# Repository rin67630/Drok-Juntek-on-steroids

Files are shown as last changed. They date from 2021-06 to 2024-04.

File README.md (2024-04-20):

# Drok&Juntek on steroids.
Extend the possibilities of cheap digital power supplies with an ESP32 WiFi module

N.B.   The Software part is now on  
https://github.com/rin67630/Soft-Power2-MPPT  
cu there...

Juntek (aka MingHe) and Drok (maybe others e.g Ming-He) sell some interesting cheap programmable buck converter modules e.g.:
- DPS3806         (60V/6A boost/buck converter) https://www.aliexpress.com/item/1005001591485527.html
- Buck3603        (36V/3A buck converter) https://www.aliexpress.com/item/32872687512.html
- BST900          (36V/90V boost converter https://www.aliexpress.com/item/1005002006504263.html
- Drok low Power  (60V/8A buck converter) https://www.aliexpress.com/item/32862110549.html  
- Drok high power (80V/12A buck converter) https://www.aliexpress.com/item/32863179021.html  
*(links only given to identify the modules, you are encouraged to procure the devices from your favourite source)  

They are all controlled by a pluggable control board, which stages a STM microcontroller and a 4x7 digit LED display.  
The 4 push-buttons to control the operations are clumsy and the seven segment display is everything but comfortable.  


My idea was to get rid of the original control module, and to replace it by an ESP32 WiFi enabled microcontroller in order to boost it's usability,
give full internet control and provide tons of features... 

Drok and Juntek are using the same analog control principle:  on the left side, the connector gets two PWM control inputs (voltage and current) and deliver two corresponding analog control feedback outputs all in the range 0..2,1V.  
On the right side, the connector provides GND and 5V at ~200mA.  

I used a TTGO ESP32 with an integrated TFT color display plugged onto a 6x8cm prototyping board as an adapter on a Drok 6008  
showing the web interface on a smartphone:   
  
Here the version with a PCB on a Drok6012 with input and load current probes and a rotary encoder on the extension port:   


The BOM for the upgrade cost less than 20$ (the ESP TTGO, an ADS1115 module, a prototyping board, some pin headers, a few resistors and condensators...)  

## The fun can begin!
Recycling a big part of the software resources of https://github.com/rin67630/Soft-Power-MPPT, I am providing much more than just a simple programmable power supply.

### Power supply mode
The power supply is controllable by:   
- USB -Serial with a simple menu to change the set-points control, the OLED display variants, the charging profiles and print reports.  
- from everywhere in the world using the cloud dashboard service of https://thinger.io with a free limited maker account.  
This is just an example, much more will come:  


 
- using the integrated buttons of the TTGO and/or an optional rotary knob to make it more comfortable to control.  
- can optionally be remotely controlled by another "slave" TTGO module in the same WiFi area.

Over the serial port and thinger.io, many reports will be made available:  
- Energy report by the second, the minute, the hour.
- Ah, Wh Joule/Coulomb reports by the minutes, the hour, the day.
- Events of the charging process
- ...  

Beside the usual constant voltage and constant current set points, I will provide many interesting things that are not common, but very useful:

### MPPT Solar charger:
cf: https://github.com/rin67630/Soft-Power2-MPPT

### Battery Charger mode: (1)  
- charging profiles for many battery chemistries
- evaluation of the battery's internal resistance
- evaluation of the battery' capacity
- charging time series plots

### Power Source emulation: (1)  
- add a programmable internal resistance
- run a constant power mode
- emulation of solar panel / wind turbine incuding "pseudo-daily" gaussian cycles (accelerated 60x) to test solar chargers

### Programmable Load (for the Juntek buck-boost version) (1)  
- together with a flooder to dissipate the energy, the buck-boost converter can be used to discharge batteries and transfer energy from one battery to another one.  

### Maybe other useful ideas that you might have...

Last but not least everything is neatly self powered, and integrated on one single board, that plugs instead of the original controller board.  
If you wanted to revert to the original functionality, just replug the manufacturer's control board.  
There is absolutely no cable mess and even a new program can be updated over the air using a beginner's easy Arduino IDE.  
You need no additional computer to manage the dashboards, everything is done in the cloud.  
The only thing you need, is a Wifi connection.  

(1) not yet finalized...

You are invited to discuss your personal project on Discord:  
https://discord.gg/gcmSpHH3bX  (Multi purpose Hardware)  
https://discord.gg/eY5H6PMqfk  (Specific application as a MPPT Solar Charge Controller).  

Cu there!

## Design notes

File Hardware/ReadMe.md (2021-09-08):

This folder contains the schematics and hardware description of my Drok-Juntek-on-steroids solution. 

# History
On a first approach V1.0, I have used a passive circuitry with resistors and capacitors to adapt the signal levels to the ADCs of the ESP32 and -to a certain extent- compensate the intrinsic deficits of the ESP32 ADCs.  
(You can take a look at the ReadMeV1.md if you are interested)

# V2.0 

Finally with V2.0 I decided to use an I2C 16bit, 4 channel ADC  ADS1115 module to replace the very low quality ADCs of the ESP32.    
With this module, conveniently placed under the TTGO, everything becomes much easier.
This new solution uses less components, is much more precise, factory calibrated and the measuring ranges can be determined by software.
The design uses standard buck converters, an ESP32 TTGO TFT module, simple prototyping boards and a few resistors/condensators. 

 ## Bill of materials Off Board

- Juntek DSP 3606 / Drok 
- TTGO ESP32 TFT board
- ADS1115 external ADC board
- 4 x 6 cm prototyping board
- 1 x 3,3MM resistor to measure up to 58V Vin for Drok, 2k resistor to measure Vin for JuntekD3806, nothing for Juntek B3603.

 ## Bill of materials On Board


## Header pinouts (comparison between Juntek / Drok)
  

**N.B.** If you can, order female pin headers with long pins. The ESP32's socket must be soldered higher than the one of the ADS1115.  

To a certain extend it is doable with regular female headers too:  
On the ADS1115 solder the male pin headers normally, then remove the plastic part of them and cut the pins 5mm shorter.  
That way, the ADS1115 PCB sits directly on the female headers. 
Solder the female headers of the ESP32 with some space between the board and the plastic.  
That lets enough room to piggy-back both modules.  



An easier solution is to procure long male pin headers for the TTGO:
https://www.ebay.de/itm/323404971458?var=512467637501

Low profile headers for the ADS1115 are possibel too, but these are not common and quite expensive.

## Proto Wiring
It's relativly easy to wire the adapter to a prototyping board:
### Top view (component side)


The prototype is universal and fits Juntek/MingHe  and Drok DC/DC conveters.
Since they have some slight difference in the left connector, I have used jumpers.

## PCB
a PCB is now on the final stage... (Thanks to TechColab).
The PCB is designed universal for all supported DC-DC converters.





n.b. The 470μF condensator is wired horizontal, we did not have a KiCAD library for that, so it is hot rendered.
The patch fields are shown empty, normally you just will wire a few wires directly but you may poulate them with 90° headers and use prototype jumpers.
On the west side w have 2 header connectors with the analog and control pins, useful for hooking measuring probes.



Who wants raw PCBs should send me his (her) address at lazlo.lebrun < you know what to insert > gmail.com,  
I would appreciate a participation of 1€ per PCB and the postage cost (2€ for Europe), i'll mail you the different PayPal address in return.

## Schematic diagram


# V1.0 
V1.0 is obsolete, that old version used the ESP32 only as ADC and was REALLY inaccurate, see ReadMeV1.md

Enjoy!

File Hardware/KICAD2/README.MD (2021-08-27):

New optimized PCB layout Courtesy paulvdh@forum.KiCAD.info.

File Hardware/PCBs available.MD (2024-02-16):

Some of us have ordered PCBs by ten pieces and have many left.  

If you need a PCB, we will be happy to send one or two just for postage.
you may ask me or other fellowes
- lazlo.lebrun <at> gmail.com  (DE)
- michel.firholz <at> live.de (DE)

If you have PCBs to distribute especially if you are located in other countries and agree to participate, let me know.

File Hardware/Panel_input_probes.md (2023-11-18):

# Panel input Probes

With the exception of the J3603 the DC-DC converters used do not provide a measurement of the panel voltage, nor its current.  
The input voltage value is however essential to control the MPPT. 
The input current is nice to have.  
Most DC-DC converters feed back the output power to the input (the solar panel) which is first wasting a part of energy when the panel does not produce current, 
secondly an inadvertent short on the panel while the battery is connected will be an irresistible call for the magic smoke.
So we will need a diode to block the backfeed current.

Since the panel voltages and current can be pretty high the circuit for them is located away from the control board with resistors limiting the energy fed to the inputs.

All these functions will be realised in two input probes connected just before the inputs of the motherboard.



## Voltage probe + blocking diode.

The 10A Schottky diode will be directly soldered to a fork terminal for screws. On the other side the input cable will be soldered to the diode with the feed back resistor (the high side of the input voltage divisor) and finally both sides are wrapped with thermo sleeves:


## Current probe
I have used two 0.05 smd resistors in // (for mechanical stabilty) soldered to a fork terminal and to the input wire at the other side (the fork is folded to fit into the tube and unfolded after) then glued everything in a hard plastic tube. On the shunt, i have a 1kΩ resistor in series to limit the damage if the shunt burns through. Finally both sides are wrapped with thermo sleeves:


  :

And finally going to the side of my adapter board:  


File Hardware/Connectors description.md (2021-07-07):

# Connectors description

## Motherboard right connector
Luckily, the motherboard right connector has the same pinout for every DC/DC converter:
from the top to the bottom you have a 4 ground connections, 2 +5V connections ( that can approximately supply 100mA) and Tx-Rx pins, that are forwarded to the corresponding Tx-Rx connector on the motherboard.  
2 capacitors C8 and C7 will reduce the impact of the power surges from the RF-transmission to the motherboard.  


## Motherboard left connector
the motherboard left connector is not completely standardised, from the top to the bottom the three first pins carry the feedback signals for the output voltage and the output current at various locations, depending on the board make. One board has a feedback of the input voltage, most don't.  
For that reason, there adapter board will have some jumpers to marshall the signals accordingly to the A2, A3, A1 analog inputs of the ADS1115.  


## Feedback of Input voltage or current
On the Juntek 3603, the feedback of the input voltage already exists on pin3 of the left connector.  
On the Juntek 3806, the feedback of the input voltage is not provided, but the pin 3 of the left connector is free, so one can solder a feedback resistor on the motherboard.   
On DROK modules, the pin 3 is not free, so one must go over a side header to provide voltage feedback.  
The current feedback ( optional ) is always to be provided over a side header to ADC0.     

## Extension headers

the standard layout provides two extension headers:
- A Grove-compatible extension header
- A universal extension header

### Grove-compatible extension header
The Grove-compatible extension header uses the standard pinout of the Grove I2C ecosystem adding supplementary ground line and a +5V
on the prototyping board this connector is at the 2.54mm pitch, on the future PCB it should use the Grove system 2mm pitch.


### Universal extension header
The universal extension header exposes all still unused IO lines DAC/ADC lines, the I2C port and some power supply lines.
The (potential) applications are: 
- Rotary control
- I2C keyboard
- Additional I2C sensors (e.g. battery temperature, load currents, light intensity, non-related measurements )
- Additional controls like Load on-off, (I have an extension load control module with 3 FETs and 3 current/voltage feed-back measures in planing)
- and even the potential ability to control a second Drok either for a second source, or a voltage controlled load (e.g. the Juntek 3806 buck boost DC/DC  converter to charge secondary batteries at lower higher voltages)
- everything else from my mad imagination...
I have foreseen the extension connectors just to make an eventual PCB future-proof.


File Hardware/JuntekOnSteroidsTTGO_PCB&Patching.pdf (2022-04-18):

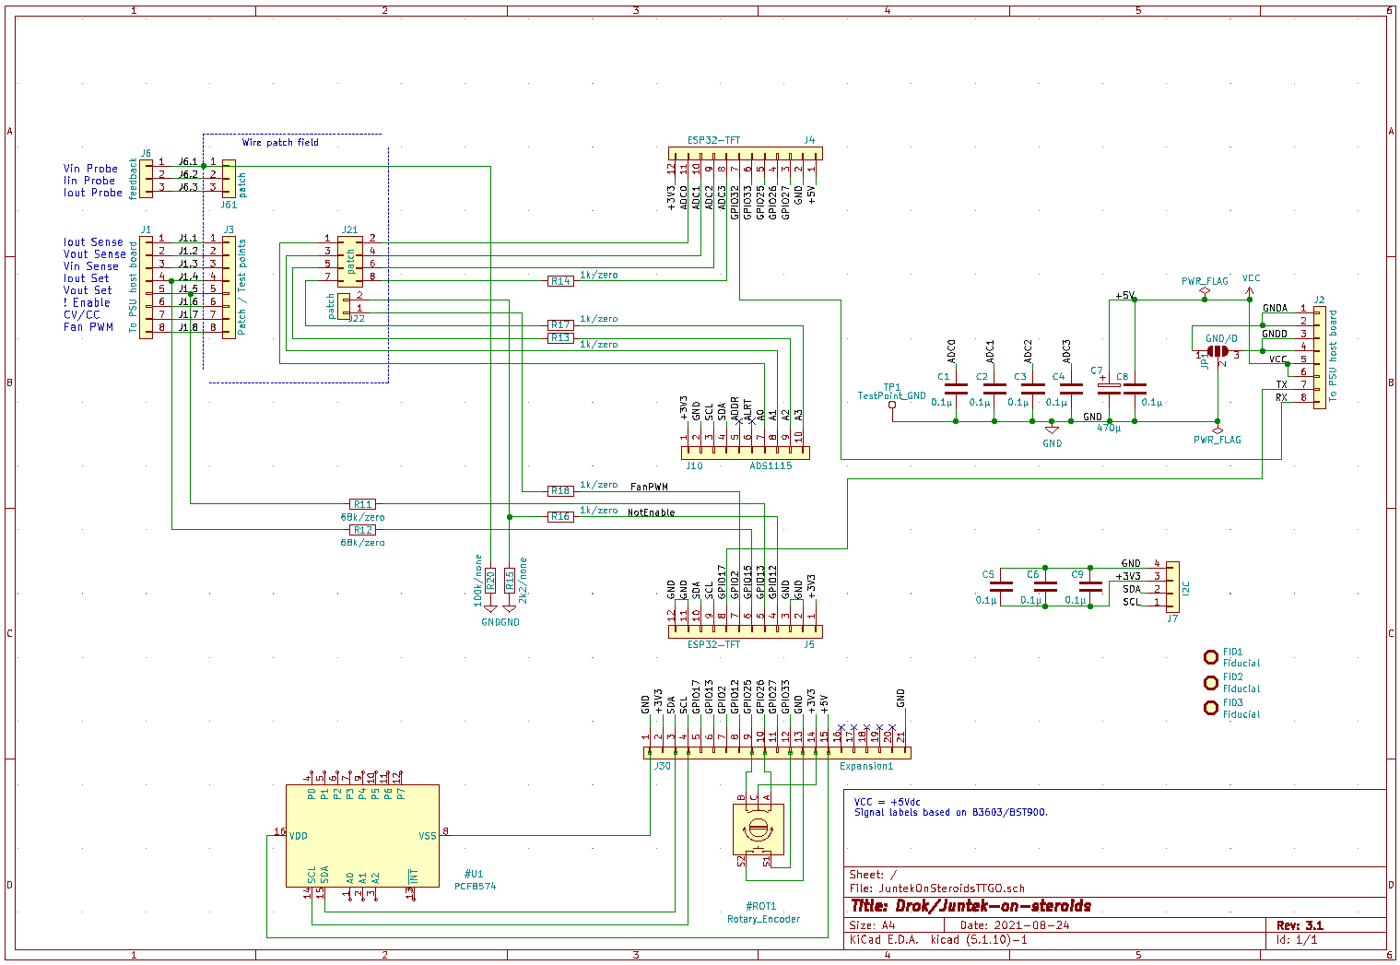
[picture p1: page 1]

# PCB without Groundfilling

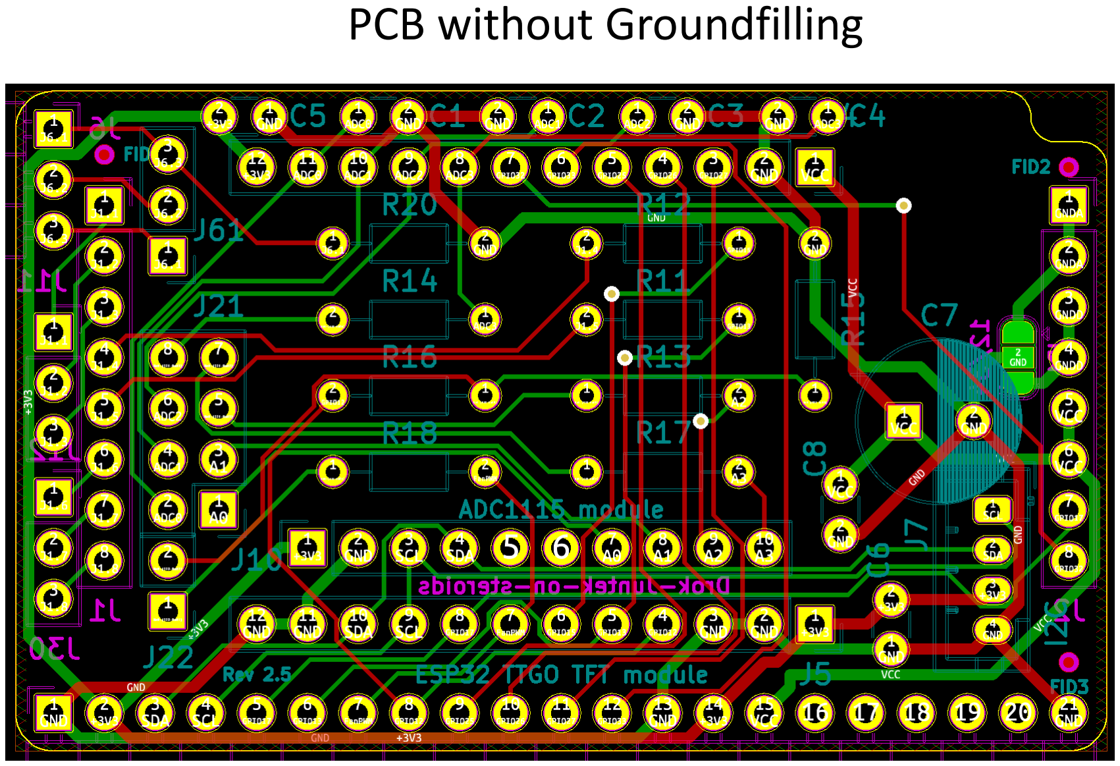
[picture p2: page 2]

# Fab´ed board rendered (F)

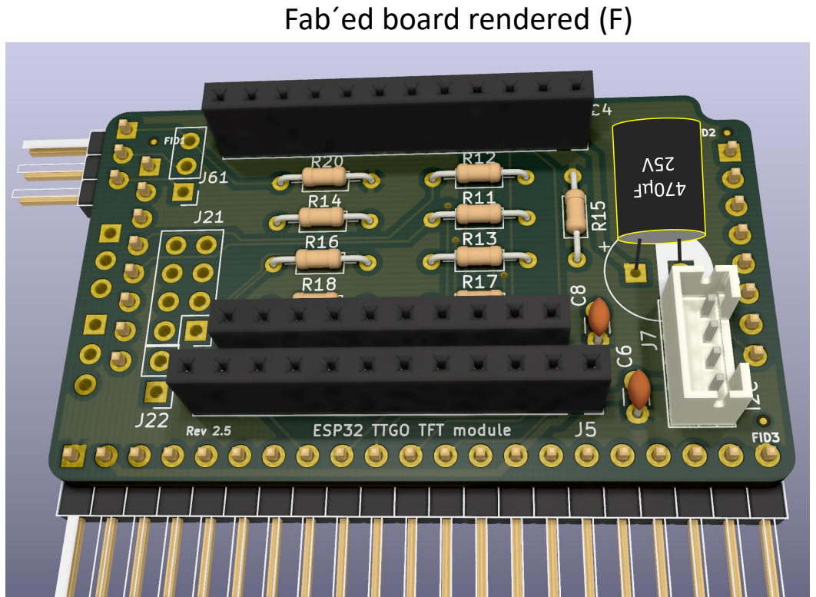
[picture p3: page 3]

B3603

# BST900

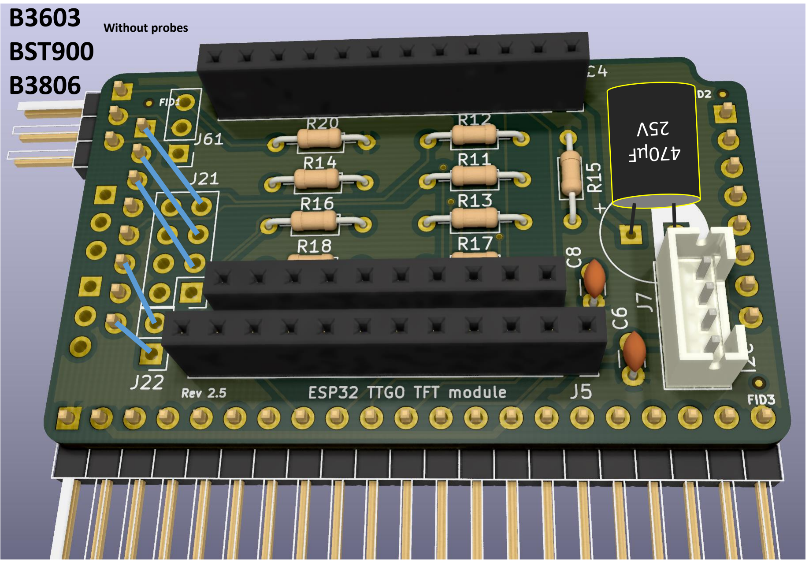
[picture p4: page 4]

B3806

Without probes

B3603

# BST900

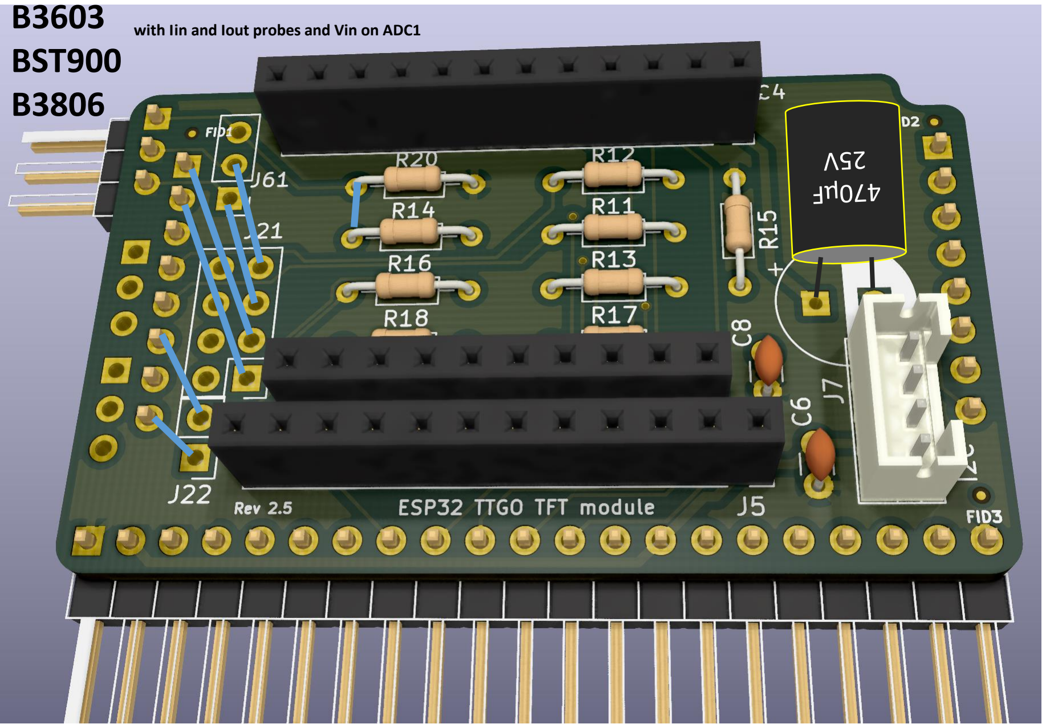
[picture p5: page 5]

B3806

with Iin and Iout probes and Vin on ADC1

B3603

# BST900

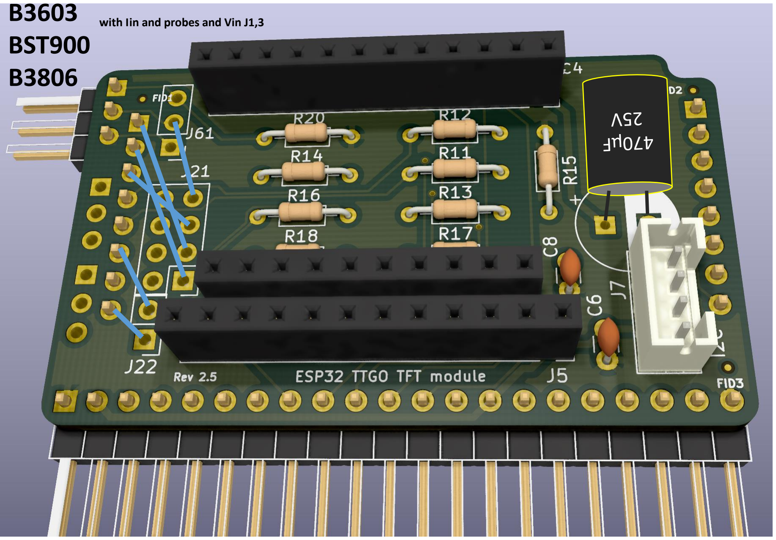
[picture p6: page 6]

B3806

with Iin and probes and Vin J1,3

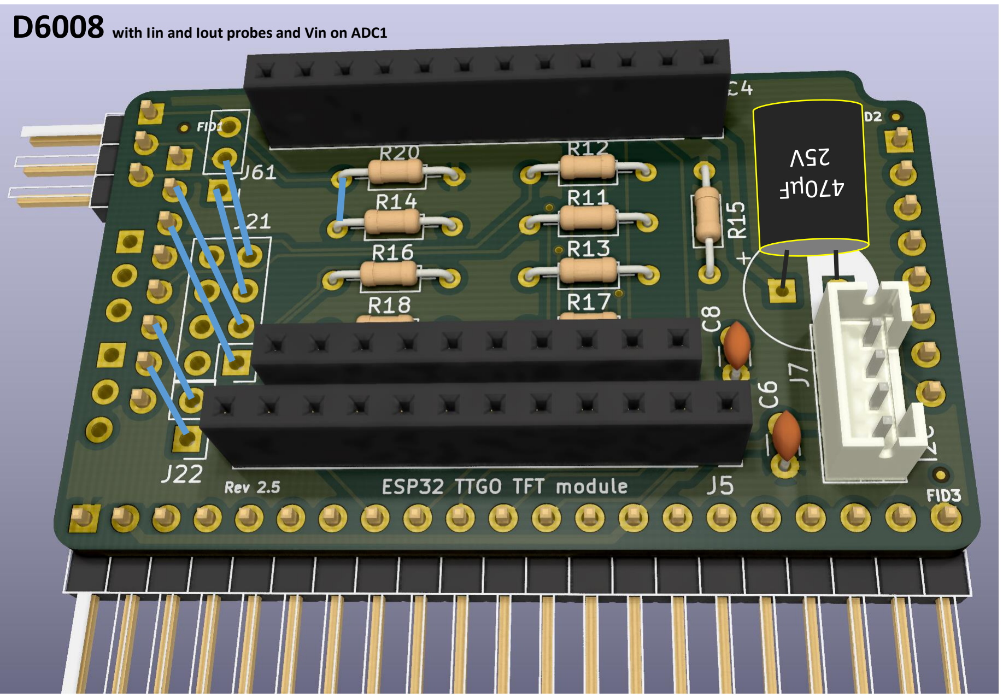
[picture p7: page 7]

D6008 with Iin and Iout probes and Vin on ADC1

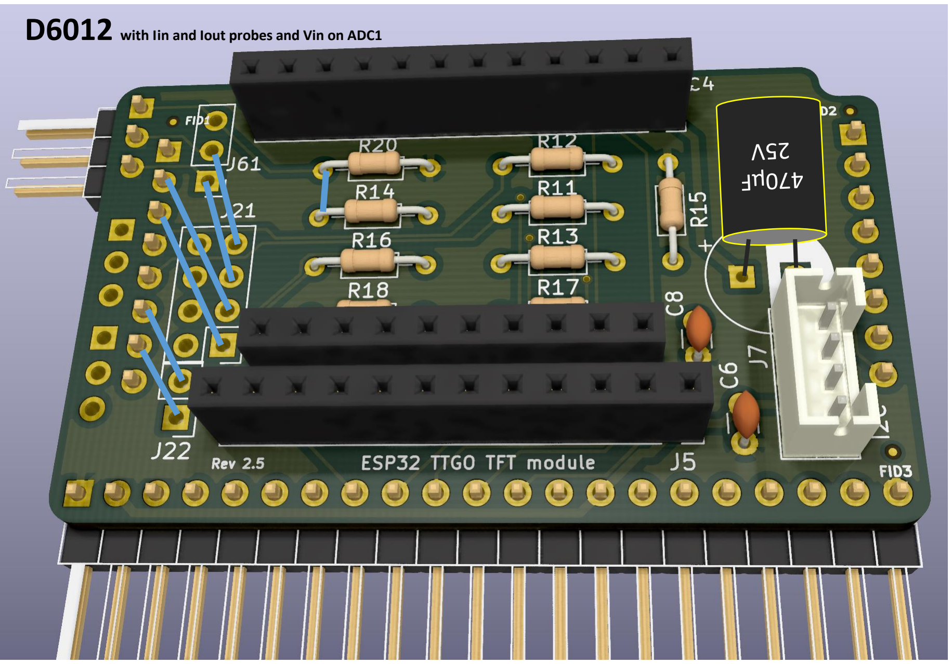
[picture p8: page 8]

D6012 with Iin and Iout probes and Vin on ADC1

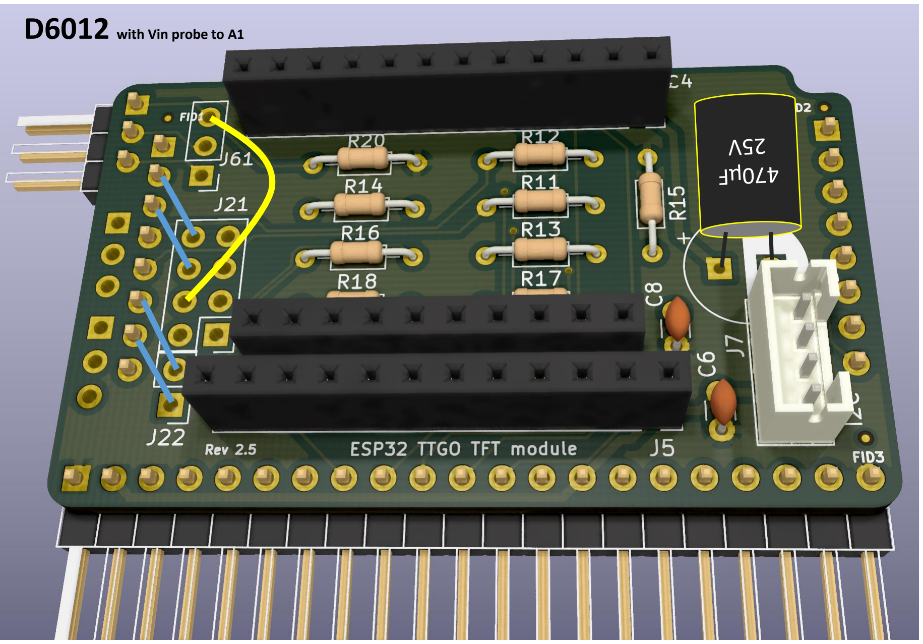
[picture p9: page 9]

D6012 with Vin probe to A1

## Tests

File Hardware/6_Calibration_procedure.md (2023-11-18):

The hardware is described in the common project Drok-Juntek-on-Steroids:  
https://github.com/rin67630/Drok-Juntek-on-steroids/tree/main/Hardware  
Enjoy!

The SoftPower HAL files are the header files containing all the specifics to the different components:
- DC-DC converters
- ESP32 boards
- Battery types

They come with usable defaults.

# Calibration procedure

The Juntek/Drok family of digital DC/DC converters are controlled ovr a 8-pin header: They provide measurement signals for current/voltage translated into a microcontroller suitable range 0..2.1V They get also PWM signals form the microcontroller in the same range.

The translation ratios depend on the respective DC/DC converter. Some ranges have a bias. I have recorded all values in header files located in libraries/SoftPower_HAL_Files:

    D6008.h
    D6012.h (D6012_PCB.h)
    J3603.h
    J3806.h

The default values should give you approximately 1% accuracy out of the box. If you want something more precise, you will need to calibrate and match the microcontroller module to the DC/DC converter.

If you know what you are doing, you might adjust them according to your own calibration procedure.
https://github.com/rin67630/Drok-Juntek-on-steroids/blob/main/Hardware/6_Calibration_procedure.md

You are encouraged to load the above mentionned files e.g. in a programming editor e.g. notepad++

To calibrate, you will need a power supply (e.g. one or two notebook-type 19V power supply (two in series) and a multimeter, plus a dummy load 
( I am e.g. using a 100W 220V halogen rod ).

If the calibration procedure uses a two point linear regression to calculate the bias and the slope of output voltage and output current.
The input current measurement is linear without bias a single point calibration is sufficient.  

The calibration procedure is using a spreadsheet and can take over data provided by the  serial protocol report sX. At the end of the easy calibration procedure the green area of the spreadsheet will be copied in the corresponding part of the DC-DC specific HAL files and be used for subsequent compile.

## Calibrating the voltage ranges

### Hardware setup:

a) provide a fixed, stable input voltage between 19V and 38V and the input of the DC/DC converter.  
b) provide a dummy load at the output of of the DC/DC converter. 
c) Connect your multimeter (set to voltage) to the output terminals 

### Measurement

Open a serial terminal program e.g. the serial monitor of the Arduino IDE.

a) Select screen 2 [return]  
b) type + until the operation is set to manual.  
c) Select screen 3 [return]   
d) type a sequence of +++[return] or ------[return] until the the output voltage (at the multimeter) is at a value of around 5V.  
   (the more ++ or -- you type in sequence the bigger the change)  
e) report the exact value in the cell I19  
f) measure the input voltage and report the exact value in the cell U19  
g) type sX to call the calibration report and copy exactly 5 lines into cell A21  

h) type a sequence of +++[return] or ------[return] until the the output voltage (at the multimeter) is at a value of around 15V (or 30V if you have a 38V input).  
   (the more ++ or -- you type in sequence the bigger the change)  
i) report the exact value in the cell I27  
j) type sX to call the calibration report and copy exactly 5 lines into cell A29



## Calibrating the current ranges

### Hardware setup:

a) type a sequence of +++[return] or ------[return] until the the output voltage is at the max battery voltage
b) Select screen 4 [return]
d) Connect your multimeter in series with the load
e) type a sequence of +++[return] or ------[return] until the the output current is at a value of around 500mA.
f) connect the output of of the DC/DC converter now to a partially discharged battery...

### Measurement

Open a serial terminal program e.g. the serial monitor of the Arduino IDE.

g) verify that the current has not changed.
h) report the exact value in the cell I41 
i) type sX to call the calibration report and copy exactly 5 lines into cell A43  

h) type a sequence of +++[return] or ------[return] until the the output current is at ca.the half of your max current.
   (ensure that your max battery voltage is not reached!)
i) report the exact value in the cell I50  
j) type sX to call the calibration report and copy exactly 5 lines into cell A52



Congratulations! The calibration procedure is finalised.

Copy of green values of the frame into the corresponding header file: e.g.:



into the respective header file (e.g. D6008.h) of the converter used, overwriting the corresponding content:

Compile. Enjoy!

    © 2021 GitHub, Inc.
    Terms
    Privacy

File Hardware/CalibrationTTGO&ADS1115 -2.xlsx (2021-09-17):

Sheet: J3603.h
Drok-Juntek-on Steroids Calibration sheet.
Needed for the calibration procedure:
-1 or two laptop 19V 3-4A power supply,
- one flooder 110V 200W or 250V 500W lamp (value not critical) ,
- your battery in partially discharged state: must accept 4-10A charge without exceeding voltage tolerances.
- a multimeter
Preparation
Connect the laptop power supply or two with outputs in series to the input of the DC/DC converter, connect the flooder to the output.
Connect the USB port of the ESP32 to a computer, open the serial monitor.
Enter 2 and so often + until your get Oper. changed to Manu.
Enter 4 and so often + or - (or turn the rotary encoder) until your get the desired current on your multimeter:
Calibrating voltages |  |  |  |  |  |  |  |  |  | Use the highest possible power supply value that the DC/DC converter supports and you have at hand. |  |  |  |  |  |  |  |  |  |  |  |  |  |  |  |  |  |  |  |  |  | PWM - Vout | PVM - Iout | FB - Vin | FB -Iin | FB -Vout | FB -Iout | FB-Iload
 |  |  |  |  |  |  |  |  |  | Put a light load on the output: e.g. a 20W /110v or 40W 220V old fashioned glow bulb .
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

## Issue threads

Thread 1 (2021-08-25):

Display not working with IS_WEMOS

delboy711, 2021-08-25:
Just trying out this project. First problem found was no output on my Oled display when using the IS_WEMOS option.

Problem traced to b_Functions.ino  the declaration for display has the SDA and SCL parameters the wrong way around

`#ifdef CONTR_IS_WEMOS`
`SSD1306Wire display(0x3c, I2C_SCL, I2C_SDA);                  //OLED 128*64 soldered`
`#endif`

should be
`SSD1306Wire display(0x3c, I2C_SDA, I2C_SCL);`

The only other issue I have had is with the library paths. The Arduino IDE does not find the libraries  unless I set the relative path such as
`#include "libraries/SoftPower_HAL_Files/FLA12-100Ah.h"`

At the moment I do not have access to a power module to test it out with.  I have ordered a new BST900 to try it with.

Closed 2024-02-16.

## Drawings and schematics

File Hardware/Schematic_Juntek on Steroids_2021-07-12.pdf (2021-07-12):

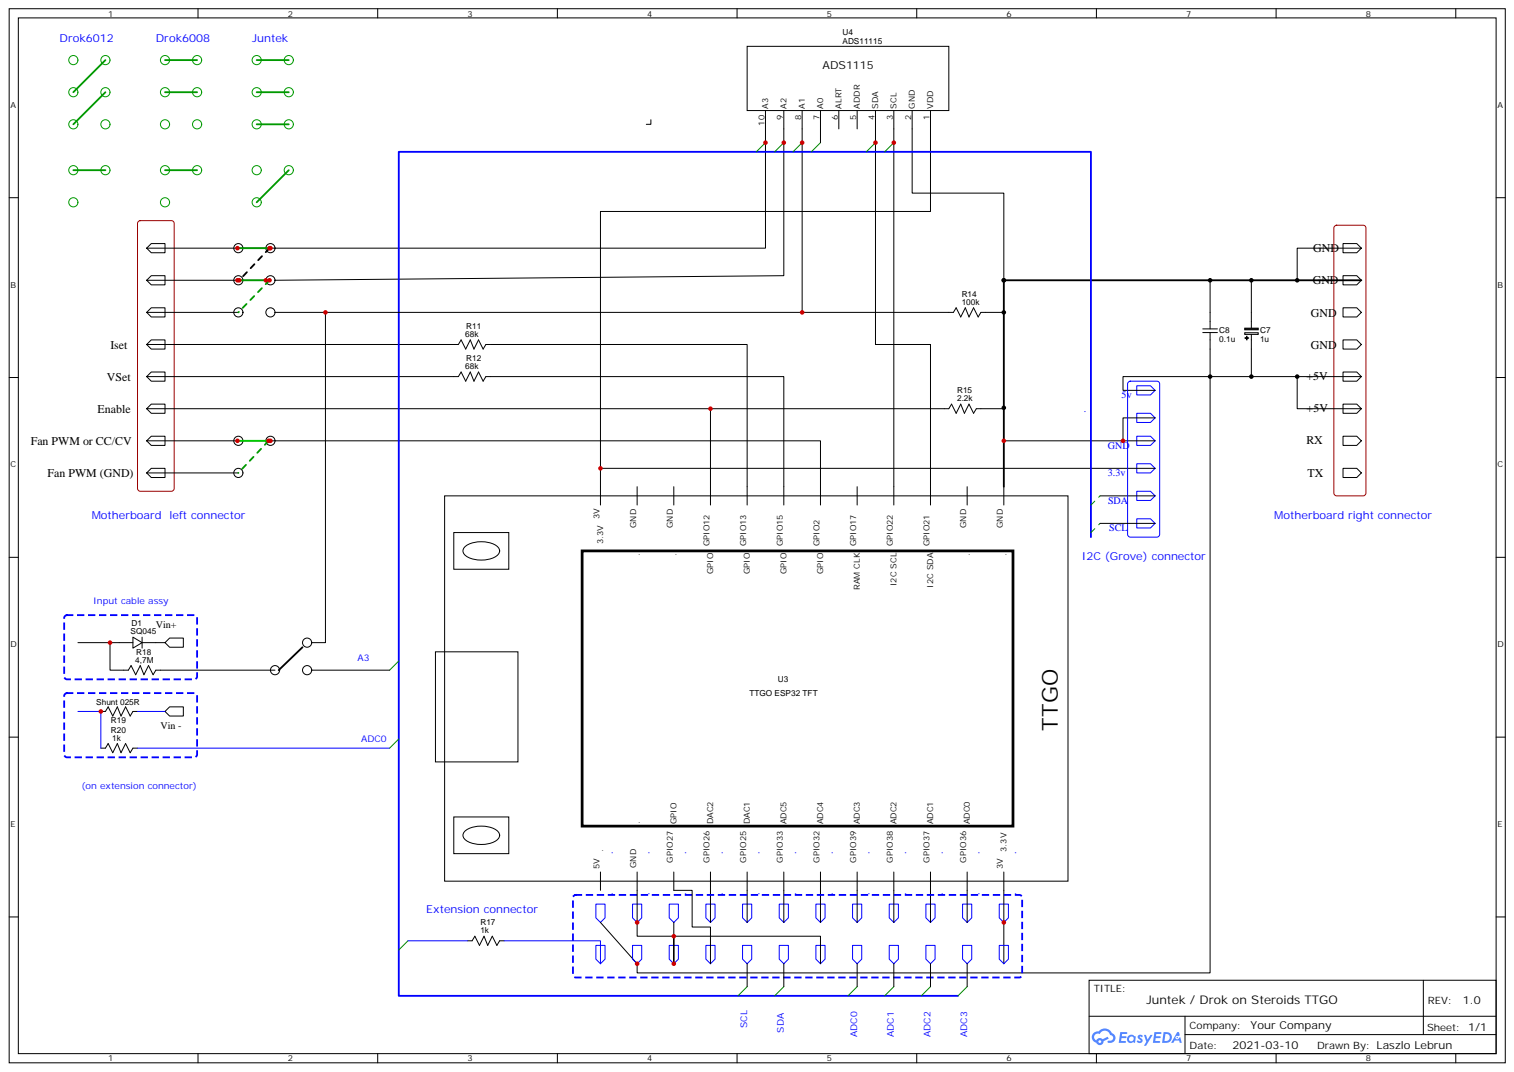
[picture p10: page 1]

Fan PWM or CC/CV

Drawn By: Laszlo Lebrun

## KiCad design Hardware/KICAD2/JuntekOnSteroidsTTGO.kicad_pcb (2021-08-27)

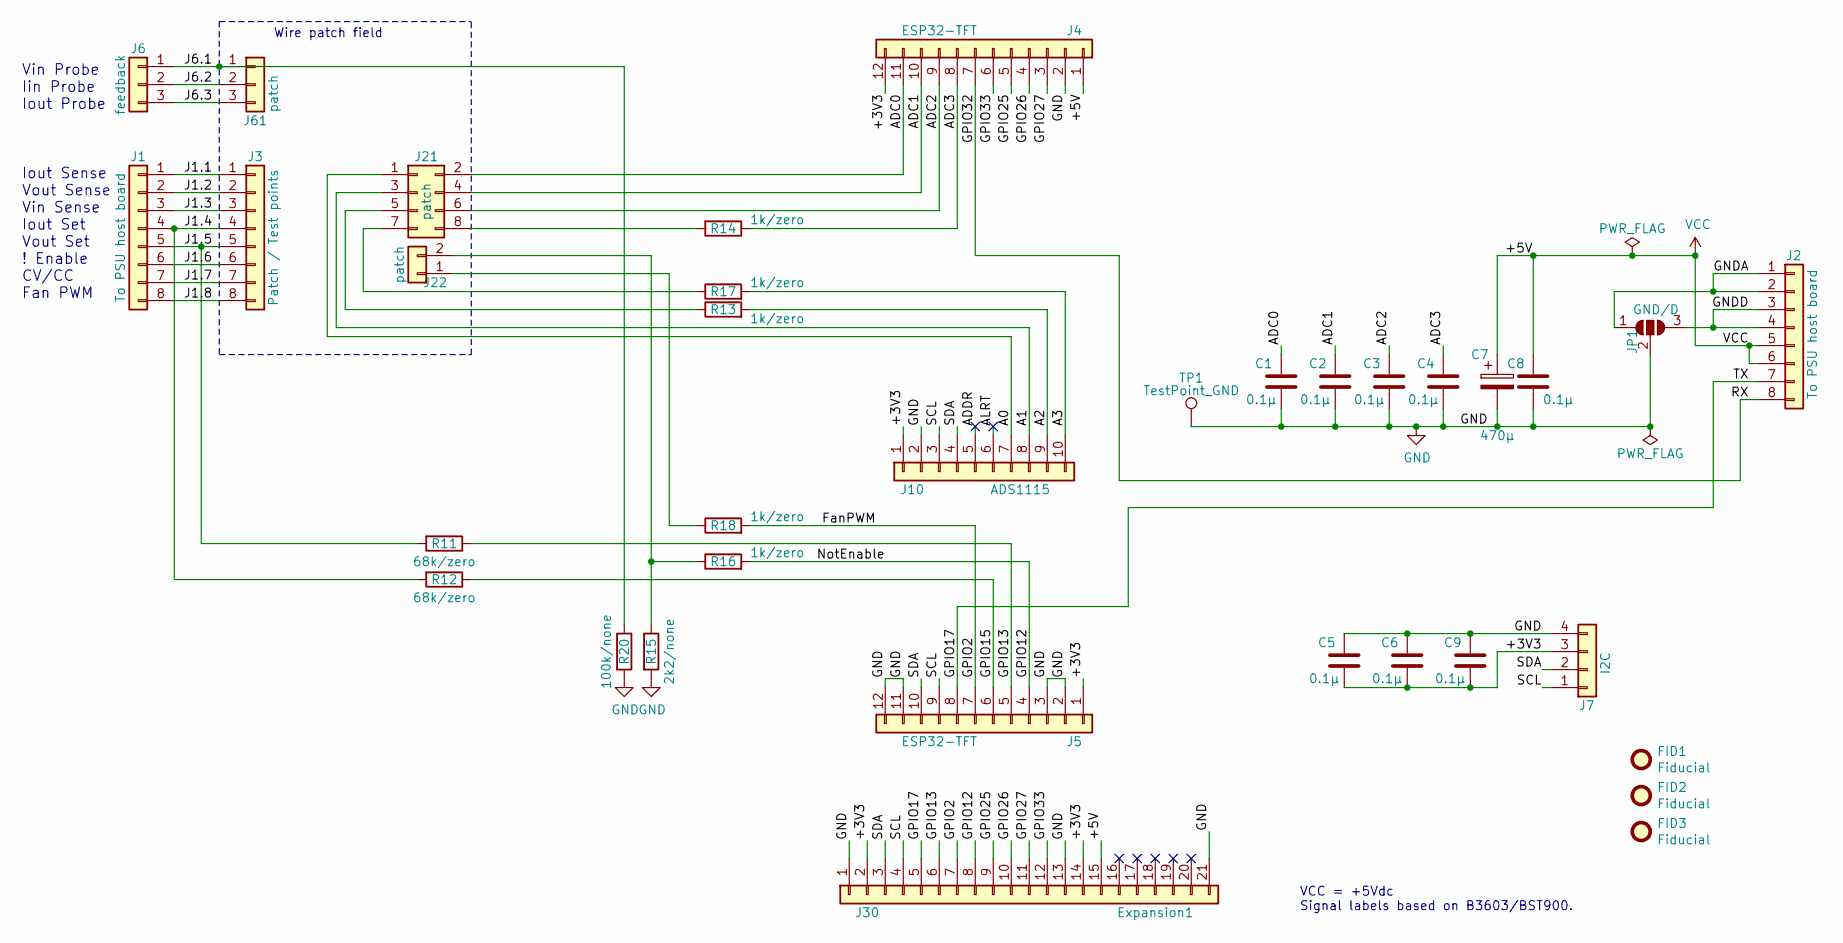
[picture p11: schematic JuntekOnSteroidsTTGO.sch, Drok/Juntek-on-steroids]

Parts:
C1, C2, C3, C4, C5, C6, C8, C9: 0.1µ; C_Disc_D3.0mm_W1.6mm_P2.50mm
C7: 470µ; CP_Radial_D8.0mm_P3.50mm
FID1, FID2, FID3: Fiducial; Fiducial_0.5mm_Mask1mm
J1, J2: To PSU host board; PinHeader_1x08_P2.54mm_Vertical
J3: Patch / Test points; PinHeader_1x08_P2.54mm_Vertical
J4, J5: ESP32-TFT; PinSocket_1x12_P2.54mm_Vertical
J6: feedback; PinHeader_1x03_P2.54mm_Horizontal
J7: I2C; JST_PH_B4B-PH-K_1x04_P2.00mm_Vertical
J10: ADS1115; PinSocket_1x10_P2.54mm_Vertical
J21: patch; PinHeader_2x04_P2.54mm_Vertical
J22: patch; PinHeader_1x02_P2.54mm_Vertical
J30: Expansion1; PinHeader_1x21_P2.54mm_Horizontal
J61: patch; PinHeader_1x03_P2.54mm_Vertical
JP1: GND/D; SolderJumper-3_P1.3mm_Open_RoundedPad1.0x1.5mm
R11, R12: 68k/zero; R_Axial_DIN0204_L3.6mm_D1.6mm_P7.62mm_Horizontal
R13, R14, R16, R17, R18: 1k/zero; R_Axial_DIN0204_L3.6mm_D1.6mm_P7.62mm_Horizontal
R15: 2k2/none; R_Axial_DIN0204_L3.6mm_D1.6mm_P7.62mm_Horizontal
R20: 100k/none; R_Axial_DIN0204_L3.6mm_D1.6mm_P7.62mm_Horizontal
TP1: TestPoint_GND; Pin_D1.3mm_L11.0mm

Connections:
/+3V3: C5.2, C6.2, C9.2, J4.12, J5.1, J7.3, J10.1, J30.2, J30.14
/A0: J10.7, J21.1
/A1: J10.8, J21.3
/A2: J10.9, R13.2
/A3: J10.10, R17.2
/ADC0: C1.1, J4.11, J21.2
/ADC1: C2.1, J4.10, J21.4
/ADC2: C3.1, J4.9, J21.6
/ADC3: C4.1, J4.8, R14.1
/FanPWM: J5.7, J30.7, R18.2
/GNDA: J2.1, J2.2, JP1.1 (A)
/GNDD: J2.3, J2.4, JP1.3 (B)
/GPIO12: J5.4, J30.8, R16.2
/GPIO13: J5.5, J30.6, R11.1
/GPIO15: J5.6, R12.1
/GPIO17: J2.7, J5.8, J30.5
/GPIO25: J4.5, J30.9
/GPIO26: J4.4, J30.10
/GPIO27: J4.3, J30.11
/GPIO32: J2.8, J4.7
/GPIO33: J4.6, J30.12
/J1.1: J1.1, J3.1
/J1.2: J1.2, J3.2
/J1.3: J1.3, J3.3
/J1.4: J1.4, J3.4, R12.2
/J1.5: J1.5, J3.5, R11.2
/J1.6: J1.6, J3.6
/J1.7: J1.7, J3.7
/J1.8: J1.8, J3.8
/J6.1: J6.1, J61.1, R20.1
/J6.2: J6.2, J61.2
/J6.3: J6.3, J61.3
/SCL: J5.9, J7.1, J10.3, J30.4
/SDA: J5.10, J7.2, J10.4, J30.3
GND: C1.2, C2.2, C3.2, C4.2, C5.1, C6.1, C7.2, C8.2, C9.1, J4.2, J5.2, J5.3, J5.11, J5.12, J7.4, J10.2, J30.1, J30.13, J30.21, JP1.2 (C), R15.2, R20.2, TP1.1
unnamed: J21.5, R13.1
unnamed: J21.7, R17.1
unnamed: J21.8, R14.2
unnamed: J22.1, R18.1
unnamed: J22.2, R15.1, R16.1
VCC: C7.1, C8.1, J2.5, J2.6, J4.1, J30.15

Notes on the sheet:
VCC = +5Vdc Signal labels based on B3603/BST900.
Wire patch field
Vin Probe Iin Probe Iout Probe
Iout Sense Vout Sense Vin Sense Iout Set Vout Set ! Enable CV/CC Fan PWM

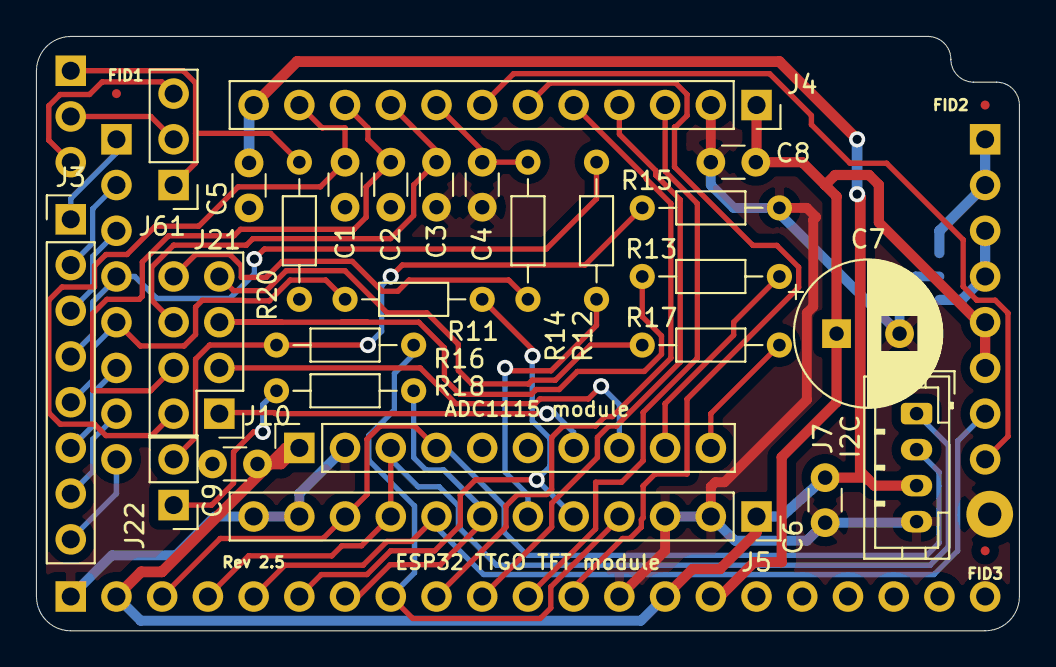
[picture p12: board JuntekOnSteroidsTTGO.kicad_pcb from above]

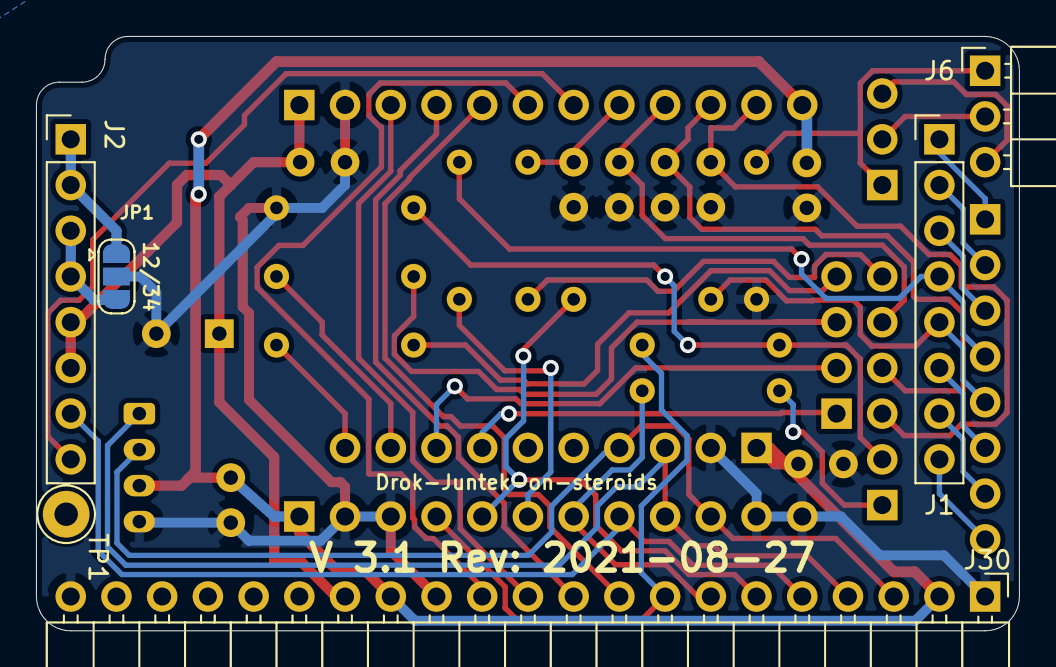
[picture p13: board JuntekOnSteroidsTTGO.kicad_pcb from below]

Board: 2 copper layers, 54.6 x 33.0 mm, 35 parts (6 on the bottom side), 41 nets.

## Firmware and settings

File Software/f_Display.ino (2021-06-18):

void displayRun()
{
  yield();

  rotary_onButtonClick();
  encoderChanged = rotaryEncoder.encoderChanged();
  if (not digitalRead(BUTTON_UP) || (not buttonPressed && encoderChanged > 0))
  {
    encoderChanged = 0;
    ++ displayPage;
    cycleDisplay = false;
    if (displayPage >= 7) displayPage = 7;
    tft.fillScreen(TFT_BLACK);
  }

  if (not digitalRead(BUTTON_DOWN) || (not buttonPressed && encoderChanged < 0))
  {
    encoderChanged = 0;
    -- displayPage;
    cycleDisplay = false;
    if (displayPage < 0 ) displayPage = 0;
    tft.fillScreen(TFT_BLACK);
  }

#ifdef BOARD_IS_TTGO  // TTGO e_SPI TFT 240*135 pixel
  if ((Second % 10 == 5) && (cycleDisplay)) // every 6 seconds
  {
    ++ displayPage;
    if (displayPage >= 5) displayPage = 1;
    tft.fillScreen(TFT_BLACK);
  }

  if (displayPage)   // Draw frame elements (if not displayPage = 0)
  {
    // Setpoint line
    setBrightness (BRIGHTNESS);

    // Time line
    tft.setTextColor(TFT_GREY, TFT_BLACK); tft.setCursor(0, 110, 4);
    buffTimeData();  tft.print(charbuff);
    tft.setTextColor(TFT_PURPLE, TFT_BLACK) ; tft.println(Runtime);
    tft.fillRect(0, 130, 120, 2, TFT_BLACK); //clear seconds progress bar
    tft.fillRect(0, 130, Second * 2, 2, TFT_PURPLE); //display seconds progress bar
    tft.setTextColor(TFT_PURPLE, TFT_BLACK) ;

    // Fan Graph
    tft.fillRect(231, 30, 6, 78, TFT_GREY);             //clear fan progress bar
    tft.fillRect(231, 30, 6, 78 - PWM_Fan * 0.076, TFT_BLACK);

    // Button description
    if (buttonPressed)
    {
      tft.setTextColor(TFT_BLACK, TFT_DARKGREY);    // print the button meanings
    } else {
      tft.setTextColor(TFT_BLACK, TFT_WHITE);
    }
    tft.setCursor(225, 0, 4);
    tft.print(">");
    tft.setCursor(225, 113, 4);
    tft.print("<");
    
    // Setpoint Line
    tft.setTextSize(1);
    tft.setTextColor(TFT_WHITE, TFT_BLACK);  tft.setCursor(0, 0, 2);
    sprintf(charbuff, "Setpoints: %05.2fV | %05.2fA | ", dashboard.SetVout, dashboard.SetIout) ;  tft.println(charbuff);
  }

  switch (displayPage)
  {
    case 0 :
      setBrightness (0);
      break;

    case 1 :     // Volt /Ampere  Display (output)
      // Page name
      tft.setTextColor(TFT_WHITE, TFT_DARKGREY);
      tft.setCursor(186, 0, 2);  tft.print(" V/A ");  // highlight CV

      // Variables
      tft.setTextColor(TFT_GREEN, TFT_BLACK) ;
      tft.setCursor(10, 16, 7); sprintf(charbuff, "%05.2f ", dashboard.Vout); tft.print(charbuff);
      tft.setCursor(160, 34, 4); tft.print("Volt");
      tft.setTextColor(TFT_VERMILON, TFT_BLACK) ;
      tft.setCursor(10, 64, 7); sprintf(charbuff, "%05.2f ", dashboard.Iout); tft.print(charbuff);
      tft.setCursor(160, 85, 4); tft.print("Amp");
      break;

    case 2 :     // Volt /Ampere  Display (intput)
      // Page name
      tft.setTextColor(TFT_WHITE, TFT_DARKGREY);
      tft.setCursor(186, 0, 2);  tft.print(" Inp ");  // highlight CV

      // Variables
      tft.setTextColor(TFT_GOLD, TFT_BLACK) ;
      tft.setCursor(10, 16, 7); sprintf(charbuff, "%05.2f ", dashboard.Vin); tft.print(charbuff);
      tft.setCursor(160, 34, 4); tft.print("Volt");
      tft.setTextColor(TFT_VERMILON, TFT_BLACK) ;
      tft.setCursor(10, 64, 7); sprintf(charbuff, "%05.2f ", dashboard.Iin); tft.print(charbuff);
      tft.setCursor(160, 85, 4); tft.print("Amp");
      break;
      
    case 3 :    // CV Display
      // Setpoint highlight
      if (buttonPressed)
      {
        tft.setTextColor(TFT_BLACK, TFT_WHITE);  tft.setCursor(65, 0, 2);   // highlight CV
        sprintf(charbuff, "%06.2fV", dashboard.SetVout) ;  tft.print(charbuff);
        dashboard.SetVout += float(encoderChanged * abs(encoderChanged)) / 100;
      }

      // Page name
      tft.setTextColor(TFT_WHITE, TFT_DARKGREY);  tft.setCursor(186, 0, 2);   // highlight CV
      tft.print(" CV ");

      // Variables
      tft.setTextColor(TFT_GREEN, TFT_BLACK) ;
      tft.setCursor(10, 16, 7); sprintf(charbuff, "%05.2f ", dashboard.Vout); tft.print(charbuff);
      tft.setCursor(160, 34, 4); tft.print("Volt");
      tft.setCursor(10, 64, 7); sprintf(charbuff, "%05.2f ", dashboard.SetVout); tft.print(charbuff);
      tft.setCursor(160, 85, 4); tft.print("SetP.");
      break;

    case 4 :     // CC Display      
    // Setpoint Highlight
      if (buttonPressed)
      {
        tft.setTextColor(TFT_BLACK, TFT_WHITE); tft.setCursor(125, 0, 2);  // highlight CC
        sprintf(charbuff, "%05.2fA ", dashboard.SetIout) ;  tft.print(charbuff);
        dashboard.SetIout += float(encoderChanged * abs(encoderChanged)) / 100;
      }

      // Page name
      tft.setTextColor(TFT_WHITE, TFT_DARKGREY);  tft.setCursor(186, 0, 2);   // highlight CV
      tft.print(" CC ");

      // Variables
      tft.setTextColor(TFT_VERMILON, TFT_BLACK) ;
      tft.setCursor(10, 16, 7); sprintf(charbuff, "%05.2f ", dashboard.Iout); tft.print(charbuff);
      tft.setCursor(160, 34, 4); tft.print("Amp");
      tft.setCursor(10, 64, 7); sprintf(charbuff, "%05.2f ", dashboard.SetIout); tft.print(charbuff);
      tft.setCursor(160, 85, 4); tft.print("SetP.");
      break;

    case 5 :     // Power Supply Display
    // Setpoint Highlight
      if (buttonPressed)
      {
        tft.setTextColor(TFT_BLACK, TFT_WHITE); tft.setCursor(125, 0, 2);  // highlight CC
        sprintf(charbuff, "%05.2fA ", dashboard.SetIout) ;  tft.print(charbuff);
        dashboard.SetIout += float(encoderChanged * abs(encoderChanged)) / 100;
      }

      // Page name
      tft.setTextColor(TFT_WHITE, TFT_DARKGREY);  tft.setCursor(186, 0, 2);   // highlight CV
      tft.print(" PS ");

      // Variables
      tft.setTextColor(TFT_GOLD, TFT_BLACK) ;  tft.setCursor(0, 25, 4);
      sprintf(charbuff, "%06.2fVi ", dashboard.Vin); tft.print(charbuff);
      tft.setTextColor(TFT_GREEN, TFT_BLACK) ; tft.setCursor(110, 25, 4);
      sprintf(charbuff, "%06.3fVo ", dashboard.Vout); tft.println(charbuff);
      tft.setTextColor(TFT_VERMILON, TFT_BLACK) ; tft.setCursor(0, 55, 4);
      sprintf(charbuff, "%06.3fA ", dashboard.Iout); tft.println(charbuff);
      tft.setTextColor(TFT_VERMILON, TFT_BLACK) ; tft.setCursor(110, 55, 4);
      sprintf(charbuff, "%06.2fAh ", Ahout); tft.println(charbuff);
      tft.setTextColor(TFT_BLUE, TFT_BLACK); tft.setCursor(0, 85, 4);
      sprintf(charbuff, "%06.2fW ", dashboard.Wout); tft.println(charbuff);
      tft.setTextColor(TFT_BLUE, TFT_BLACK); tft.setCursor(110, 85, 4);
      sprintf(charbuff, "%06.1fWh ", Whout); tft.println(charbuff);
      break;

    case 6 :     // BAT Display
      // Page name
      tft.setTextColor(TFT_WHITE, TFT_DARKGREY);  tft.setCursor(186, 0, 2);   // highlight CV
      tft.print(" Bat ");
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

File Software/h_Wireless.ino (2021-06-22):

void wirelessRun()
{
  if (WiFi.status() != WL_CONNECTED)
  {
    WiFi.disconnect();
    WiFi.reconnect();
  }
#if defined (THINGER)

  MillisMem = millis();
  thing.handle();
  if (NewMinute)
  {
    thing.stream("measure");
    thing.stream("status");
  }

#if defined (WRITE_BUCKETS)
  if (triglEvent)     thing.write_bucket("EVENT", "EVENT");
  if (DayExpiring)    thing.write_bucket("DAY", "DAY");
  if (HourExpiring)   thing.write_bucket("HOUR", "HOUR");
  if (MinuteExpiring) thing.write_bucket("MIN", "MIN");
#endif

  if (Minute % 6 == 5)           //every 6 minutes update persistence data
  {
    pson Ah_prop;// 0..23=hour, 25=current, 26=Ah 24h, 27= AhDay
    Ah_prop["00h"] = Ah[0];
    Ah_prop["01h"] = Ah[1];
    Ah_prop["02h"] = Ah[2];
    Ah_prop["03h"] = Ah[3];
    Ah_prop["04h"] = Ah[4];
    Ah_prop["05h"] = Ah[5];
    Ah_prop["06h"] = Ah[6];
    Ah_prop["07h"] = Ah[7];
    Ah_prop["08h"] = Ah[8];
    Ah_prop["09h"] = Ah[9];
    Ah_prop["10h"] = Ah[10];
    Ah_prop["11h"] = Ah[11];
    Ah_prop["12h"] = Ah[12];
    Ah_prop["13h"] = Ah[13];
    Ah_prop["14h"] = Ah[14];
    Ah_prop["15h"] = Ah[15];
    Ah_prop["16h"] = Ah[16];
    Ah_prop["17h"] = Ah[17];
    Ah_prop["18h"] = Ah[18];
    Ah_prop["19h"] = Ah[19];
    Ah_prop["20h"] = Ah[20];
    Ah_prop["21h"] = Ah[21];
    Ah_prop["22h"] = Ah[22];
    Ah_prop["23h"] = Ah[23];
    Ah_prop["LastHour"] = Ah[25];
    Ah_prop["Yesterday"] = Ah[27];
    Ah_prop["Today"] = Ah[26];
    thing.set_property("AhStat", Ah_prop);

    pson LTData;
    LTData["initial_voltage"] = persistence.initial_voltage;
    LTData["voltageAt0H"] = persistence.voltageAt0H ;
    LTData["voltageDelta"] = persistence.voltageDelta ;
    LTData["HourVSum"] = persistence.HourVSum;
    LTData["HourISum"] = persistence.HourISum;
    LTData["HourWSum"] = persistence.HourWSum;
    LTData["HourSamples"] = persistence.HourSamples;
    LTData["CycleVSum"] = persistence.CycleVSum;
    LTData["CycleISum"] = persistence.CycleISum;
    LTData["CycleWSum"] = persistence.CycleWSum;
    LTData["CycleSamples"] = persistence.CycleSamples;
    LTData["AhMode"] = persistence.AhMode;
    thing.set_property("LongTerm", LTData);
  }
#endif // defined Thinger

#if defined (PUBLISH_REPORT)               // Read with NetCat Bash command nc -u -l [UDP_PORT +1]
  if (DayExpiring || triglEvent)
  {
    UDP.beginPacket(REPORT_TARGET, UDP_PORT + 1);
    if (DayExpiring)
    {
      UDP.printf("\nHour|   Ah    |    V    |    W    |\n");
      for  (byte n = 0; n < 31; n++)
      {
        if (n == 24)
        {
          UDP.printf("Extra ""hours"" 25:H-1, 26:today, 27:D-1, 28:D-2..\n");
        }
        else
        {
          UDP.printf("%02u  | %+07.3f | %+07.3f | %+07.3f |\n", n, Ah[n], VoutAvg[n], Wh[n]);
        }
      }
    }
    if (triglEvent)
    {
      UDP.printf("Event reporting to be defined");
    }
    UDP.endPacket();
  }
#endif

  if (NewMinute)
  {
#if defined (UDP_MASTER)
    memcpy(dashboard_punning, &dashboard, sizeof(dashboard));
    UDP.beginPacket(DATA_TARGET, UDP_PORT);
    UDP.write(dashboard_punning, sizeof(dashboard));
    UDP.endPacket();
#else
    yield();
#endif

    pson thing_property;
    //Periodically retrieve the PID parameters, comment out once the PID Paramters are stable
    thing.get_property ("thing_property", thing_property);
    P_value = thing_property["_P_value"]; I_value = thing_property["_I_value"]; D_value = thing_property["_D_value"]; MPPT_perturbe = thing_property["_MPPT_perturbe"];

    //Periodically save the values that must persist after reboot
    thing_property["Ah/hour"] = Ahout;
    thing_property["Wh/hour"] = Whout;
    thing_property["voltageAt0H"] =  persistence.voltageAt0H;
    thing_property["voltageDelta"] = persistence.voltageDelta;
    thing_property["InitialVoltage"] = persistence.initial_voltage;
    thing_property["HourSamples"] = persistence.HourSamples;
    thing.set_property("thing_property", thing_property, true);
    yield();
  }
}

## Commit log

2021-03-15 Preconfigured Dashboard
    Preconfigured Thinger Dashboard, replace all occurences of "User" by your user name and all occurences of "JuntekNT" by your device name.
2021-03-15 Customized User_Setup.h
    Customized User_Setup.h should replace [Arduino User Folder]/libraries/TFT_eSPI/User_Setup.h
2021-07-07 Update and rename ExtensionHeaders.MD to Connectors description.mdMD
2021-07-07 Rename Connectors description.mdMD to Connectors description.md
2021-07-07 Update Connectors description.md
2021-08-26 Create README.MD
    Here are all files needed by KiCAD to generate a PCB.
2021-08-26 Create README.MD
    Here are the Fab files to manufacture the PCB
2021-08-27 Create README.MD
    Here the PCB production files...
2022-04-18 Add files via upload
    Corrected the patch assignments to PCB
2024-02-16 Create PCBs available.MD
